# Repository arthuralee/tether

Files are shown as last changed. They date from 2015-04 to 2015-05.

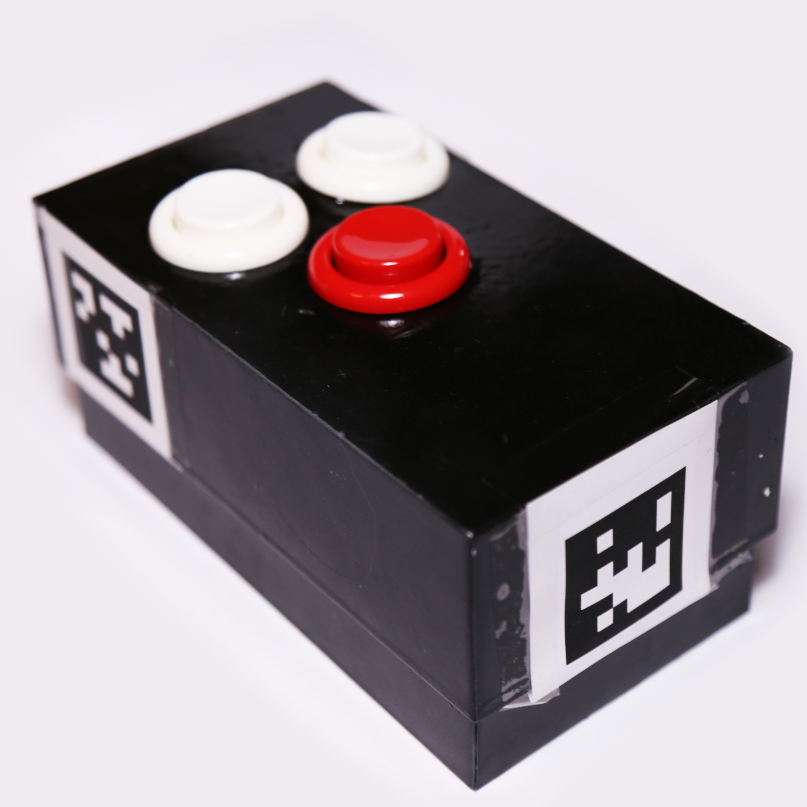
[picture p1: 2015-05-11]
poster/IMG_2027.JPG

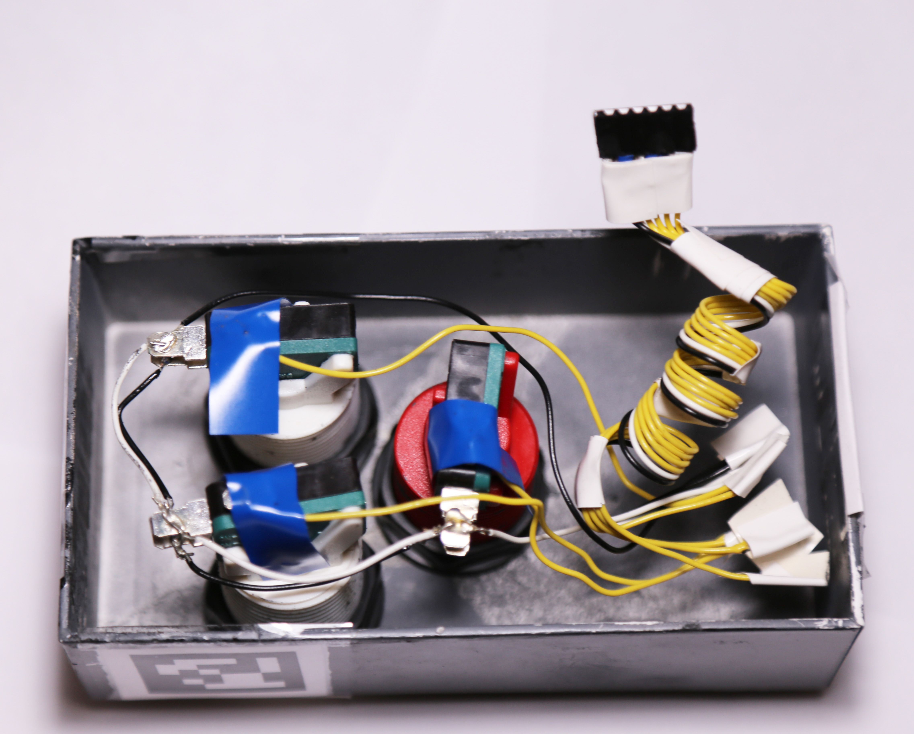
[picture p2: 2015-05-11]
poster/IMG_2029.JPG

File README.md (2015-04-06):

# Tether

## Tether provides real-time tracking of physical objects.
Tether tracks the orientation and position of an object in 3D space, making the data available for use in the construction of a 3D world.

http://www.ece.cmu.edu/~ece549/spring15/team05/

This is our project repository, which will contain code for all parts of the project.

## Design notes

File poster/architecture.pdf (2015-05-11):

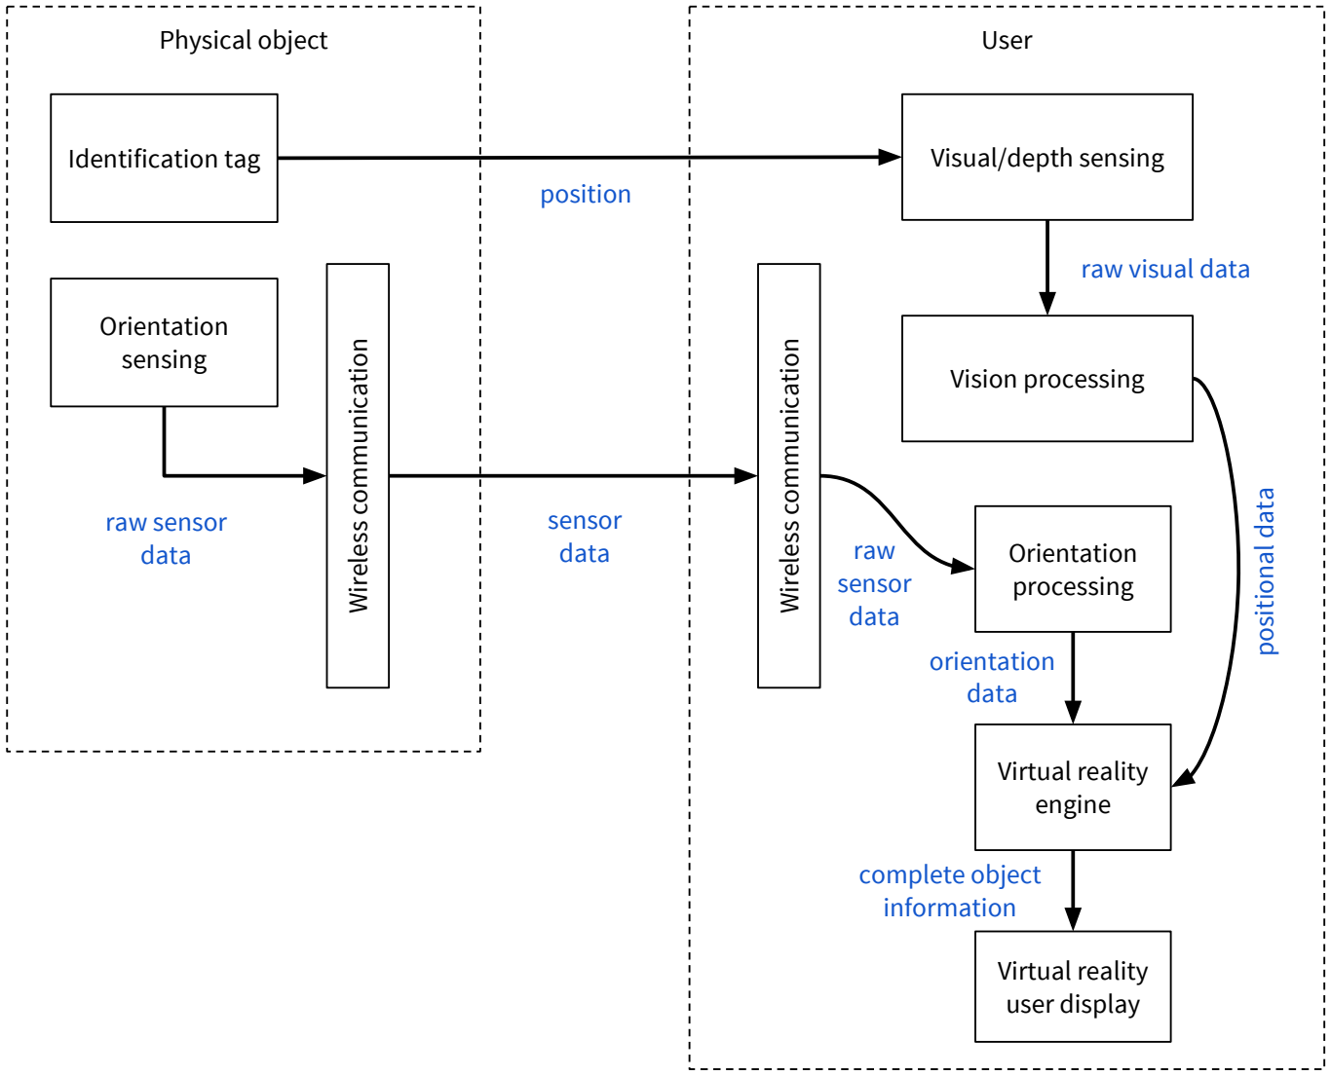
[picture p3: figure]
Physical object; User; Orientation sensing; Identification tag; Visual/depth sensing; Vision processing; Virtual reality engine; Orientation processing; Wireless communication; sensor data; Virtual reality user display; raw sensor data; position; raw visual data; positional data; orientation data; complete object information

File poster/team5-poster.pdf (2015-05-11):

# tether

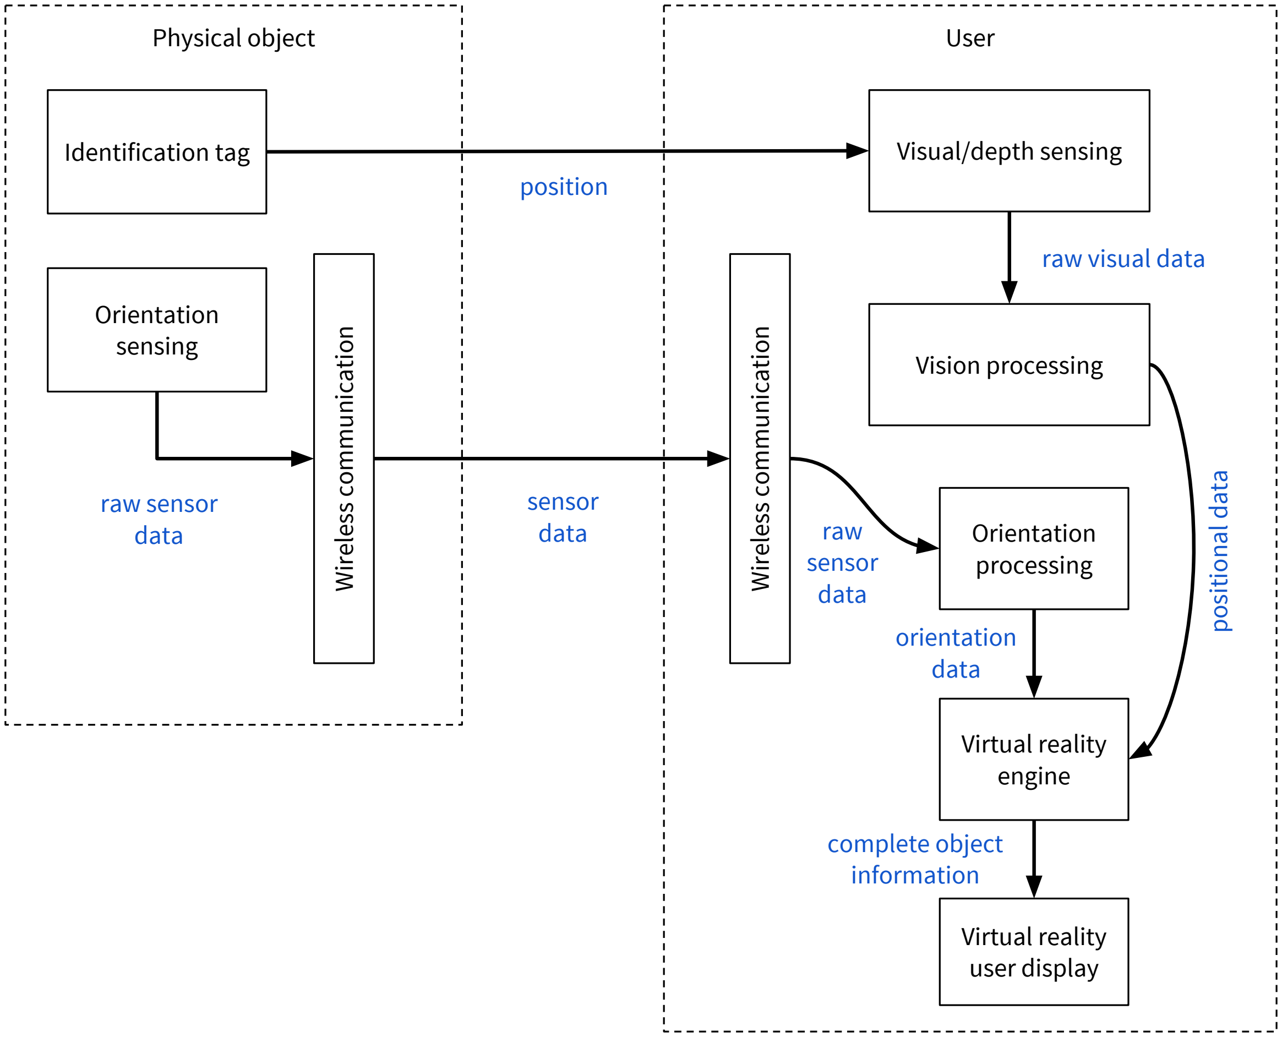
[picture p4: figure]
Physical object; User; Orientation sensing; Identification tag; Visual/depth sensing; Vision processing; Virtual reality engine; Orientation processing; Wireless communication; sensor data; Virtual reality user display; raw sensor data; position; raw visual data; positional data; orientation data; complete object information
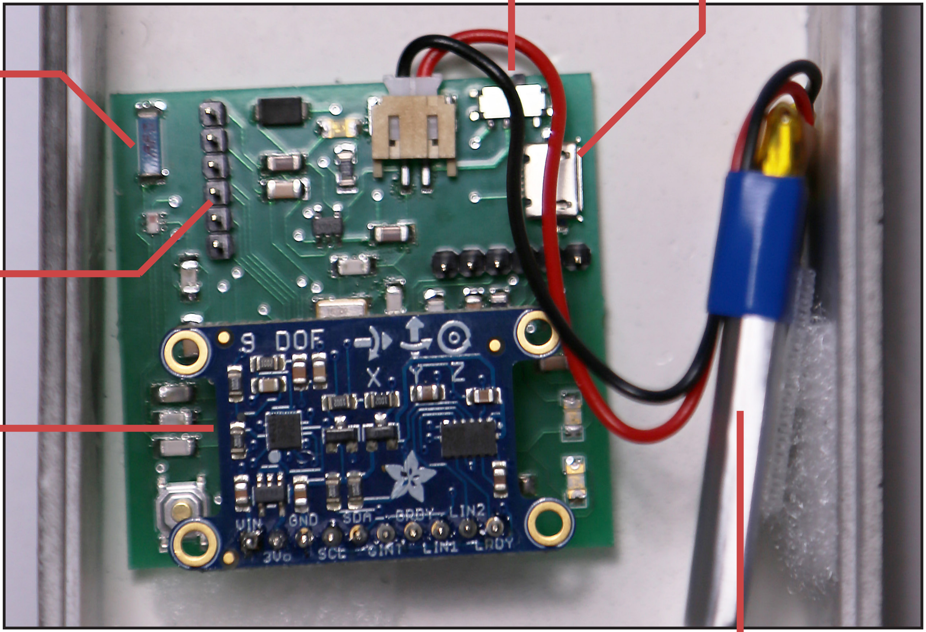
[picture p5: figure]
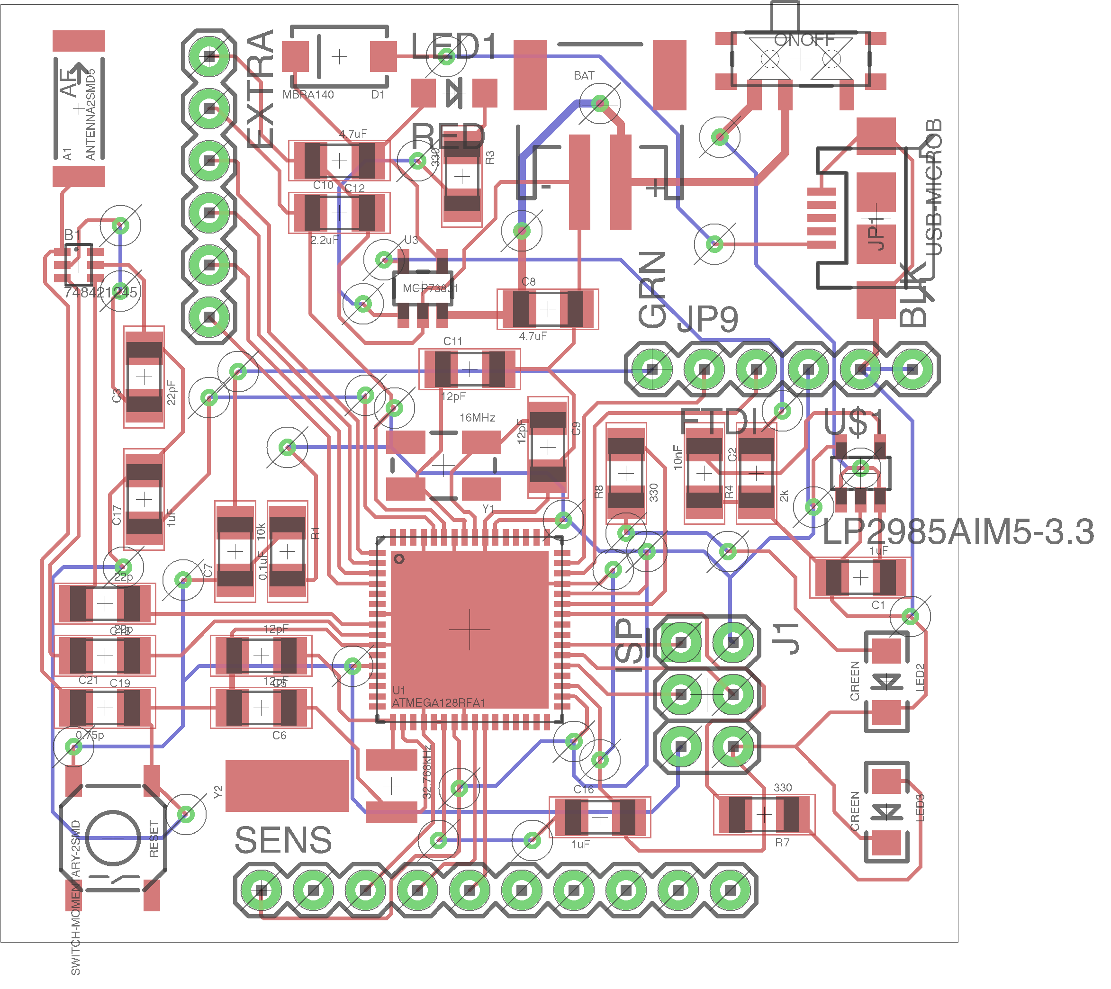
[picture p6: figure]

18-549 Embedded Systems Design - Spring 2015

Electrical & Computer Engineering Department Carnegie Mellon University

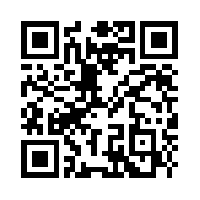
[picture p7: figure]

Tomer Borenstein
tborenst@andrew.cmu.edu

Arthur Lee
arthurle@andrew.cmu.edu

Ahmed Shalaby
akshalab@andrew.cmu.edu
Introduction | Architecture

# Sensor box design

# Hardware

Tether brings physical objects into the virtual world
so that users can interact with them in both worlds simultaneously. Tether creates a compelling way to interact with virtual objects, which could be viable in many fields from video gaming to engineering and medicine.

enclosure
april tags

buttons

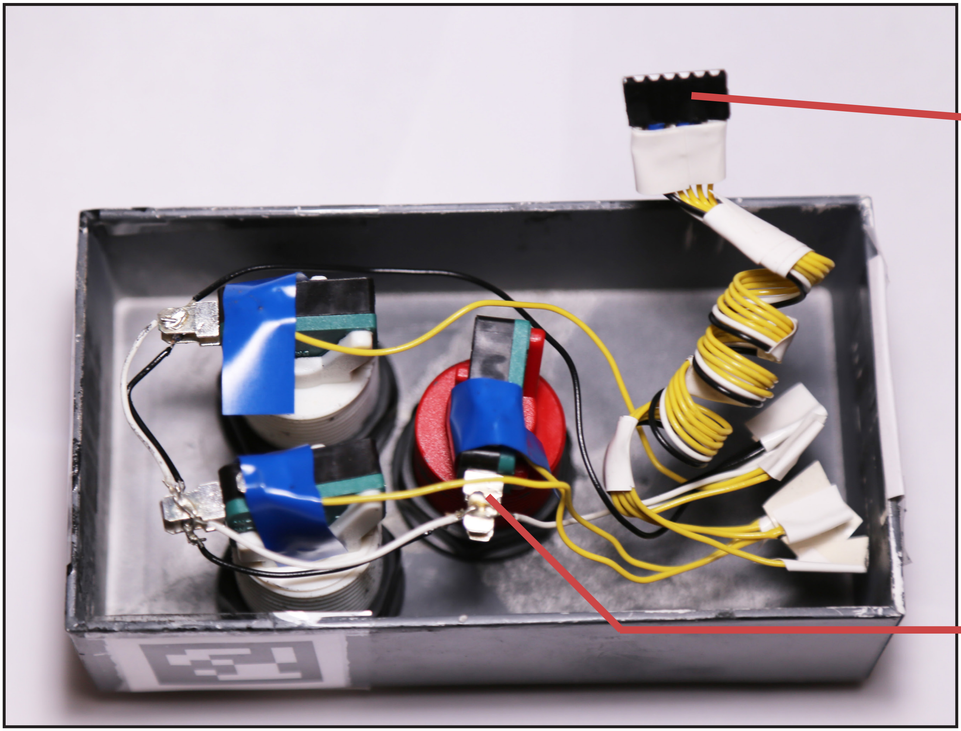
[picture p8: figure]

lithium-polymer
battery

USB
charging

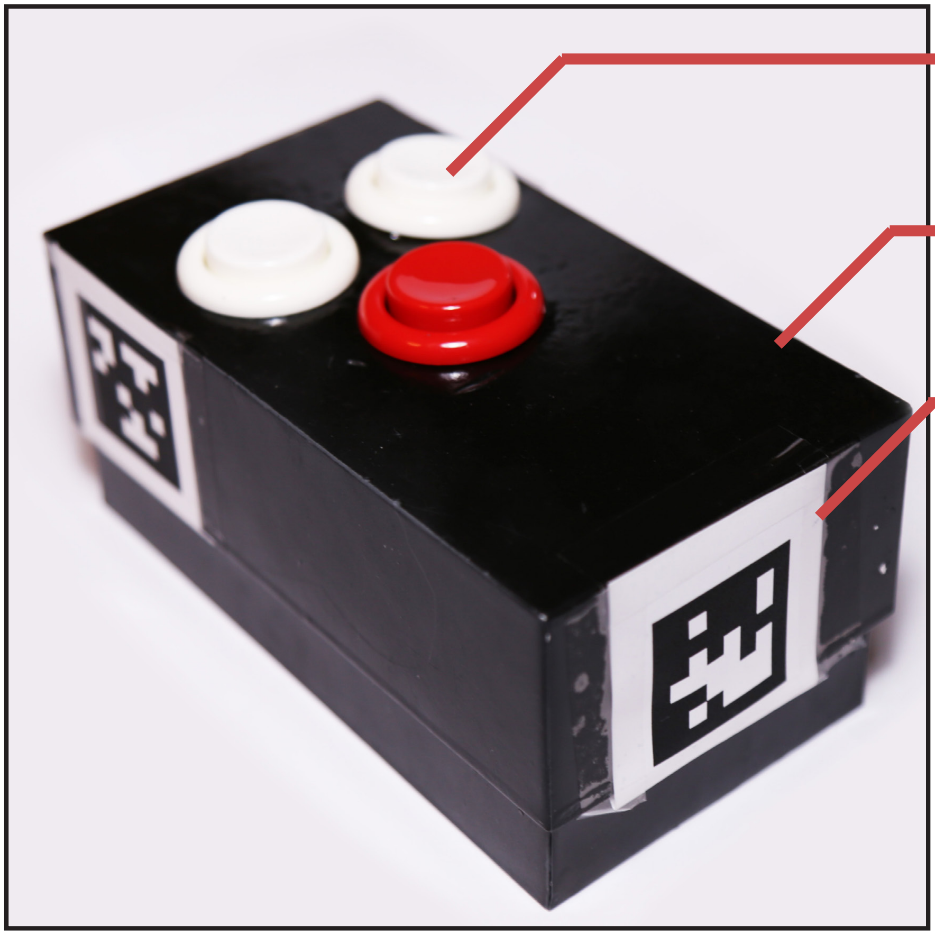
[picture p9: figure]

on-board
antenna
expansion port

9DOF sensor
breakout

arcade buttons

expansion port
connector

on/off switch

The ATMega128RFA1 has
an integrated radio, which allows us to send sensor
data wirelessly using the
802.15.4 protocol. The
receiver uses the same
PCB, and interfaces with
the computer via serial.
We connected an Adafruit 9DOF sensor breakout board to the PCB via header pins at the bottom. The expansion port on the left gives direct access to ADC so that buttons, switches and dials can easily be connected to the sensor. Additionally, the unit runs on LiPo batteries with USB charging.
We used AprilTags and a network camera to track the 3D position of the sensor box.

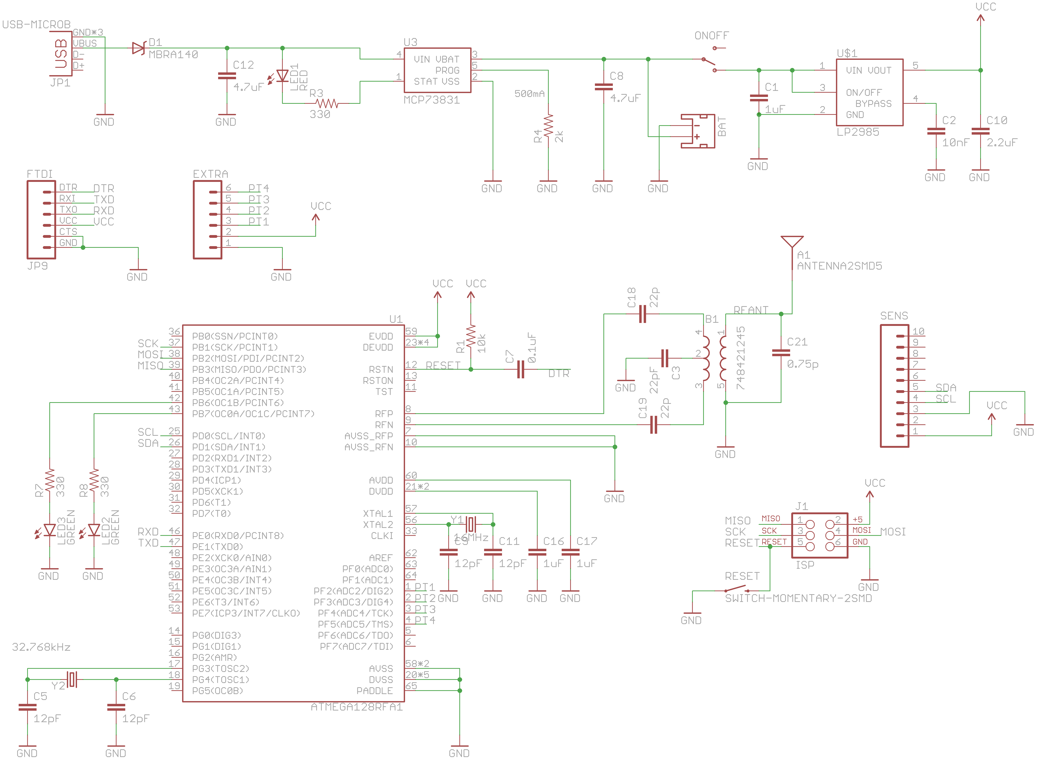
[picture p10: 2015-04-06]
website/images/media/20140401-schematic.png

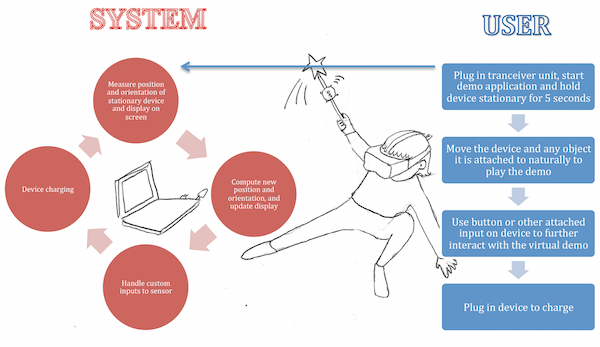
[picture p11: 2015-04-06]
website/images/behavior.png

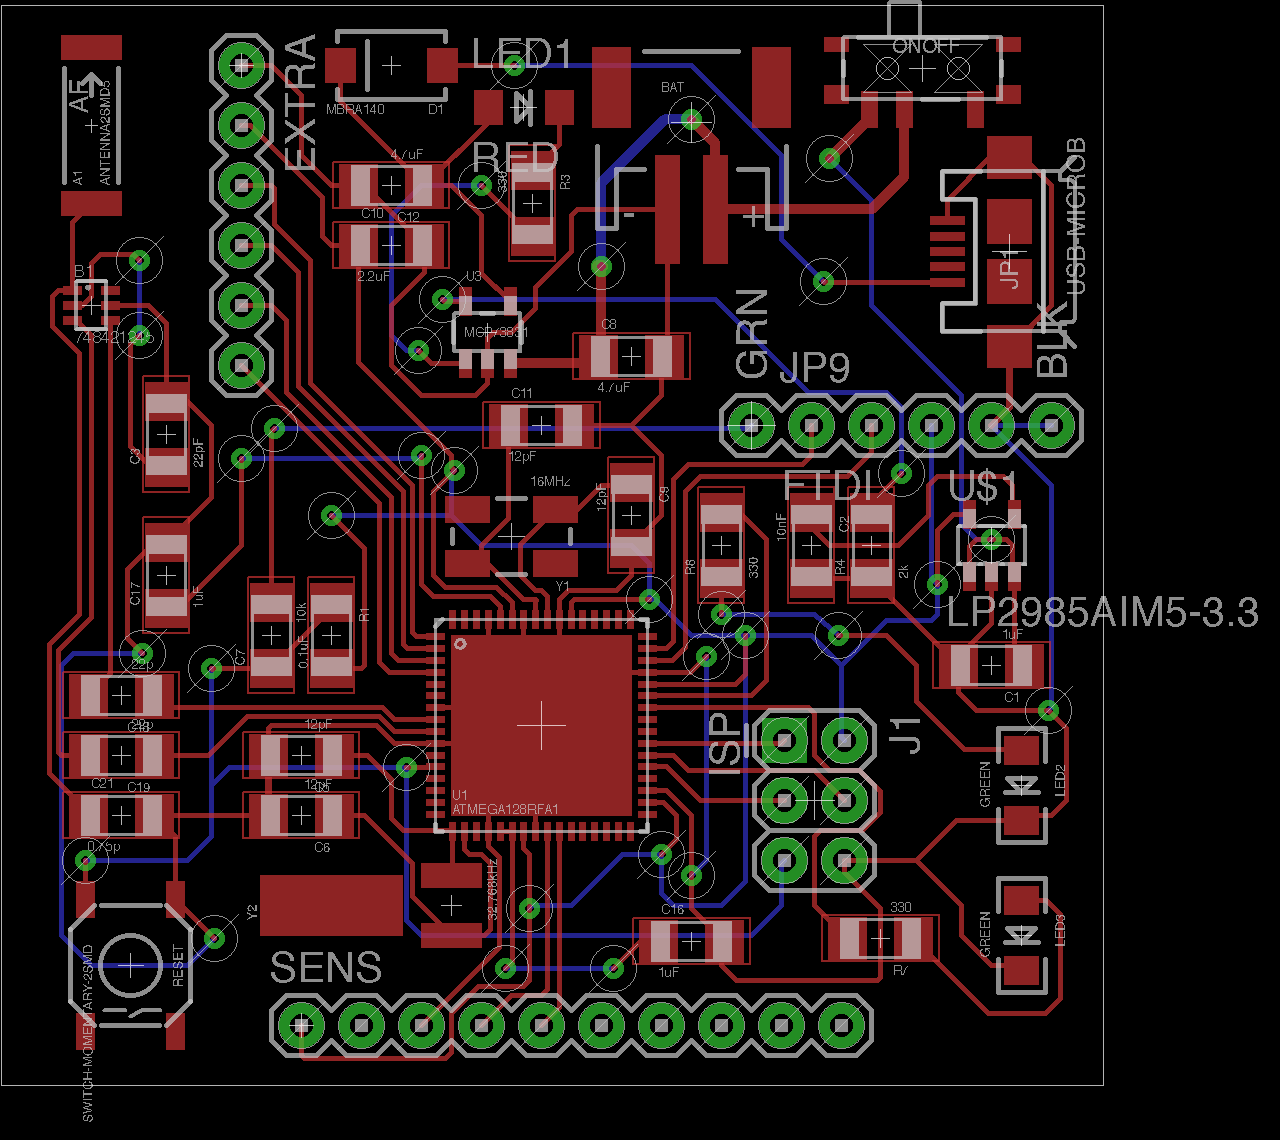
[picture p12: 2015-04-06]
website/images/media/20140401-board.png

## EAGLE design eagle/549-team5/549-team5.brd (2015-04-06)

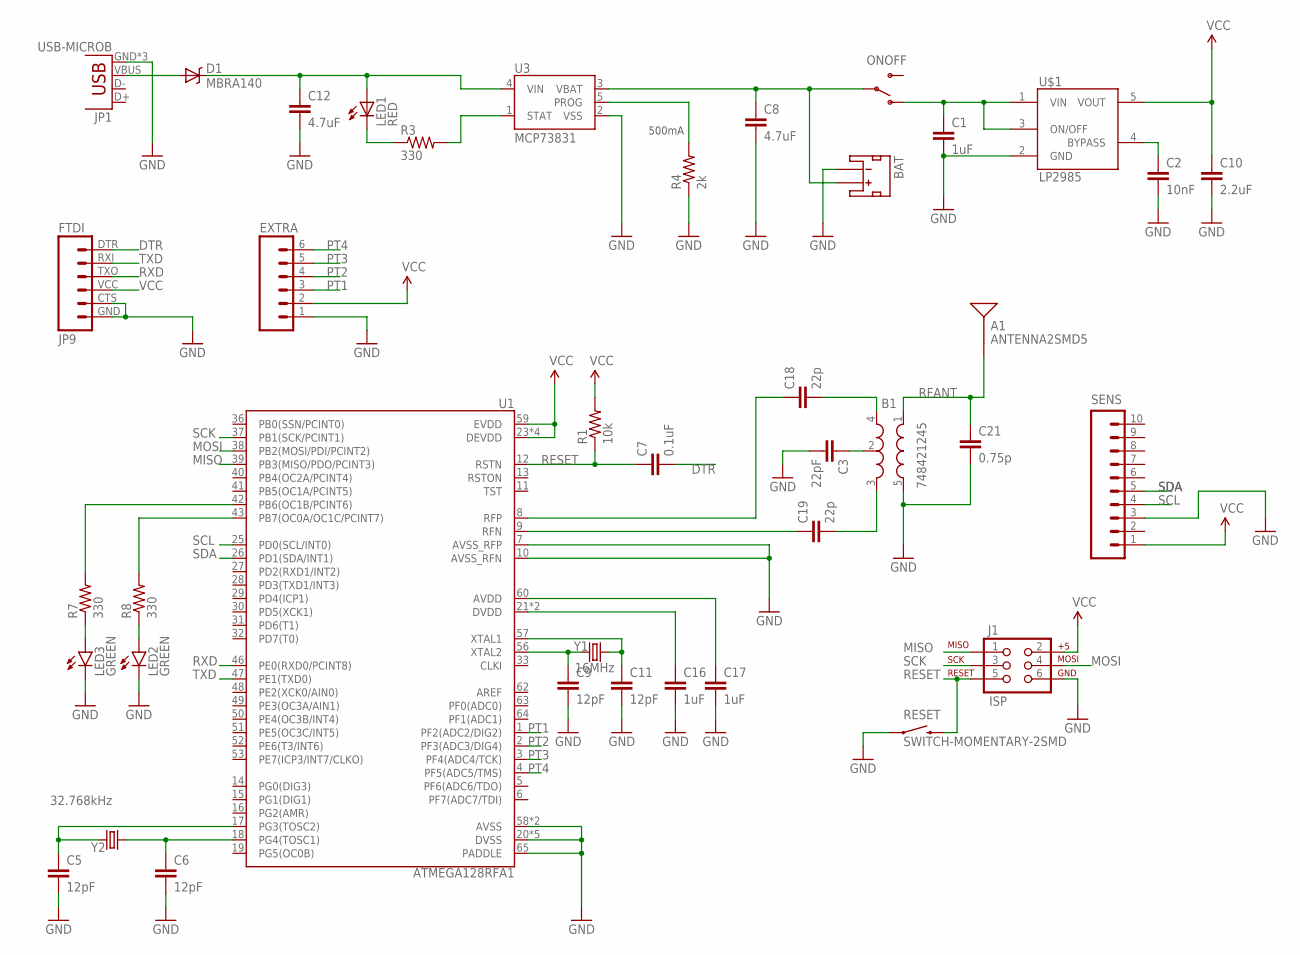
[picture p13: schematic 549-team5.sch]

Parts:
A1: ANTENNA2SMD5; ANTENNA-CHIP5
B1: 748421245; BALUN
BAT: JST_2MM_MALE; JST-2-SMD
C1, C16, C17: 1uF; 1206
C2: 10nF; 1206
C3: 22pF; 1206
C5, C6, C9, C11: 12pF; 1206
C7: 0.1uF; 1206
C8, C12: 4.7uF; 1206
C10: 2.2uF; 1206
C18, C19: 22p; 1206
C21: 0.75p; 1206
D1: MBRA140; SMA-DIODE
EXTRA: M06SILK_FEMALE_PTH; 1X06
J1: ISP; 2X3-NS
JP1: USB-MICROB
JP9: FTDI; FTDI_BASIC
LED1: RED; LED-1206
LED2, LED3: GREEN; LED-1206
ONOFF: SWITCH-SPST-SMD-A
R1: 10k; 1206
R3, R7, R8: 330; 1206
R4: 2k; 1206
RESET: SWITCH-MOMENTARY-2SMD; TACTILE-SWITCH-SMD
SENS: M10SILK_FEMALE_PTH; 1X10
U1: ATMEGA128RFA1; QFN-64
U3: MCP73831; SOT23-5
U$1: LP2985AIM5-3.3; SOT25
Y1: 16MHz; CRYSTAL-SMD-5X3
Y2: 32.768kHz; CRYSTAL-32KHZ-SMD

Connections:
AVDD: C17.1, U1.60 (AVDD)
BYPASS: C2.1, U$1.4 (BYPASS)
DTR: C7.2, JP9.DTR (1)
DVDD: C16.1, U1.21 (DVDD), U1.22 (DVDD)
GND: B1.5 (GND), BAT.1 (-), C1.2, C2.2, C3.2, C5.2, C6.2, C8.2, C9.2, C10.2, C11.2, C12.2, C16.2, C17.2, C21.2, EXTRA.1, J1.6, JP1.GND, JP1.MT1 (GND), JP1.MT2 (GND), JP9.CTS (5), JP9.GND (6), LED2.C, LED3.C, R4.1, RESET.1, SENS.3, U1.7 (AVSS_RFP), U1.10 (AVSS_RFN), U1.20 (DVSS), U1.24 (DVSS), U1.35 (DVSS), U1.45 (DVSS), U1.55 (DVSS), U1.58 (AVSS), U1.61 (AVSS), U1.65 (PADDLE), U3.2 (VSS), U$1.2 (GND)
MISO: J1.1, U1.39 (PB3(MISO/PDO/PCINT3))
MOSI: J1.4, U1.38 (PB2(MOSI/PDI/PCINT2))
unnamed: R8.2, U1.43 (PB7(OC0A/OC1C/PCINT7))
unnamed: C11.1, U1.57 (XTAL1), Y1.3 (2)
unnamed: C9.1, U1.56 (XTAL2), Y1.1
unnamed: C6.1, U1.18 (PG4(TOSC1)), Y2.X1 (1)
unnamed: C5.1, U1.17 (PG3(TOSC2)), Y2.X2 (2)
unnamed: C1.1, ONOFF.1 (O), U$1.1 (VIN), U$1.3 (ON/OFF)
unnamed: LED3.A, R7.1
unnamed: BAT.2 (+), C8.1, ONOFF.2, U3.3 (VBAT)
unnamed: B1.4 (OUT1), C18.2
unnamed: B1.3 (OUT2), C19.2
unnamed: R7.2, U1.42 (PB6(OC1B/PCINT6))
unnamed: LED2.A, R8.1
unnamed: B1.2 (GND), C3.1
unnamed: C12.1, D1.C, LED1.A, U3.4 (VIN)
unnamed: R3.2, U3.1 (STAT)
unnamed: LED1.C, R3.1
unnamed: D1.A, JP1.VBUS
PROG: R4.2, U3.5 (PROG)
PT1: EXTRA.3, U1.1 (PF2(ADC2/DIG2))
PT2: EXTRA.4, U1.2 (PF3(ADC3/DIG4))
PT3: EXTRA.5, U1.3 (PF4(ADC4/TCK))
PT4: EXTRA.6, U1.4 (PF5(ADC5/TMS))
RESET: C7.1, J1.5, R1.1, RESET.3 (2), U1.12 (RSTN)
RFANT: A1.FEED, B1.1 (IN), C21.1
RFN: C19.1, U1.9 (RFN)
RFP: C18.1, U1.8 (RFP)
RXD: JP9.TXO (3), U1.46 (PE0(RXD0/PCINT8))
SCK: J1.3, U1.37 (PB1(SCK/PCINT1))
SCL: SENS.4, U1.25 (PD0(SCL/INT0))
SDA: SENS.5, U1.26 (PD1(SDA/INT1))
TXD: JP9.RXI (2), U1.47 (PE1(TXD0))
VCC: C10.1, EXTRA.2, J1.2, JP9.VCC (4), R1.2, SENS.1, U1.23 (DEVDD), U1.34 (DEVDD), U1.44 (DEVDD), U1.54 (DEVDD), U1.59 (EVDD), U$1.5 (VOUT)

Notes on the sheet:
500mA

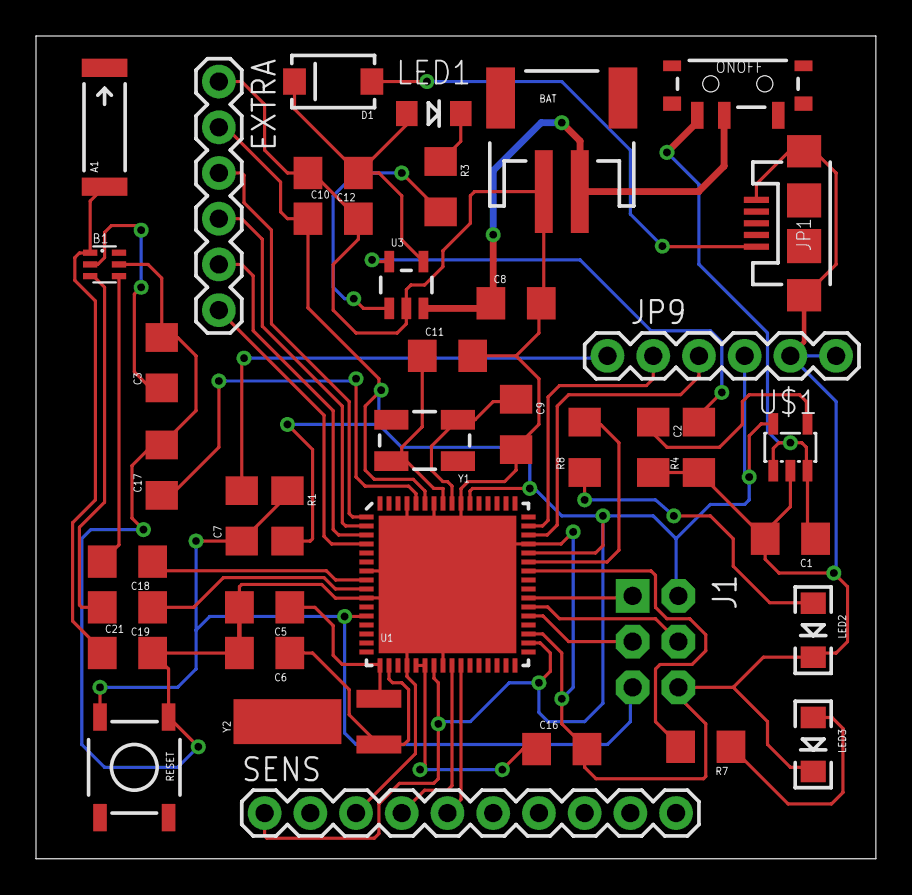
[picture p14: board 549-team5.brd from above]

Board: 2 copper layers, 46.7 x 45.7 mm, 40 parts (0 on the bottom side), 39 nets.

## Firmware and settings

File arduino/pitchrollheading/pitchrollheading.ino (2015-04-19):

#include <Wire.h>
#include <Adafruit_Sensor.h>
#include <Adafruit_LSM303_U.h>
#include <Adafruit_L3GD20_U.h>
#include <Adafruit_9DOF.h>

/* Assign a unique ID to the sensors */
Adafruit_9DOF                dof   = Adafruit_9DOF();
Adafruit_LSM303_Accel_Unified accel = Adafruit_LSM303_Accel_Unified(30301);
Adafruit_LSM303_Mag_Unified   mag   = Adafruit_LSM303_Mag_Unified(30302);
Adafruit_L3GD20_Unified      gyr   = Adafruit_L3GD20_Unified(30303);

/* Update this with the correct SLP for accurate altitude measurements */
float seaLevelPressure = SENSORS_PRESSURE_SEALEVELHPA;

/**************************************************************************/
/*!
    @brief  Initialises all the sensors used by this example
*/
/**************************************************************************/
void initSensors()
{
  if(!accel.begin())
  {
    /* There was a problem detecting the LSM303 ... check your connections */
    Serial.println(F("Ooops, no LSM303 detected ... Check your wiring!"));
    while(1);
  }
  if(!mag.begin())
  {
    /* There was a problem detecting the LSM303 ... check your connections */
    Serial.println("Ooops, no LSM303 detected ... Check your wiring!");
    while(1);
  }
  if(!gyr.begin())
  {
    /* There was a problem detecting the LSM303 ... check your connections */
    Serial.println("Ooops, no L3GD20 detected ... Check your wiring!");
    while(1);
  }
}

/**************************************************************************/
/*!

*/
/**************************************************************************/
void setup(void)
{
  Serial.begin(115200);
  
  /* Initialise the sensors */
  initSensors();
}

/**************************************************************************/
/*!
    @brief  Constantly check the roll/pitch/heading/altitude/temperature
*/
/**************************************************************************/
void loop(void)
{
  sensors_event_t accel_event;
  sensors_event_t mag_event;
  sensors_event_t gyr_event;
  sensors_vec_t   orientation;

  /* Calculate pitch and roll from the raw accelerometer data */
  if(!accel.getEvent(&accel_event)) return;
  if (dof.fusionGetOrientation(&accel_event, &mag_event, &orientation))
  {
    /* 'orientation' should have valid .roll and .pitch fields */
    Serial.print(orientation.roll); //roll
//    if(orientation.roll<=0){
//      Serial.print(-orientation.roll); //roll
//    }
//    else{
//      Serial.print(360-orientation.roll); //roll
//    }
    Serial.print(F(","));
    Serial.print(orientation.pitch); //pitch
//    if(orientation.pitch<0){
//      Serial.print(-orientation.pitch); //pitch
//    }
//    else{
//      Serial.print(360-orientation.pitch); //pitch
//    }
  }
  Serial.print(F(","));
  /* Calculate x y z from gyroscope */
  if (!gyr.getEvent(&gyr_event)) return;
  else {
    /* 'orientation' should have valid .roll and .pitch fields */
    Serial.print(gyr_event.gyro.x); //gyr x
    Serial.print(F(","));
    Serial.print(gyr_event.gyro.y); //gyr y
    Serial.print(F(","));
    Serial.print(gyr_event.gyro.z); //gyr z

  }
//  else{
//    Serial.print(F(" ")); //gyr x
//    Serial.print(F(","));
//    Serial.print(F(" ")); //gyr y
//    Serial.print(F(","));
//    Serial.print(F(" ")); //gyr z
//  }
  Serial.print(F(","));
  /* Calculate the heading using the magnetometer */
  if(!mag.getEvent(&mag_event)) return;
//  dof.magTiltCompensation(SENSOR_AXIS_Z, &mag_event, &accel_event);
  if (dof.fusionGetOrientation(&accel_event, &mag_event, &orientation))
  {
    /* 'orientation' should have valid .heading data now */
    Serial.print(orientation.heading); //Headin
  }

  Serial.println(F(""));
  delay(100);
}

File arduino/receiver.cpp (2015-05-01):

#include <Wire.h>

#include "Arduino.h"
#include "RadioFunctions.h"

void setup(void);
void loop(void);

void setup(void)
{
  Serial.begin(115200);

  rfBegin(11);

  Serial.println("Setup");

  /* Initialise the sensors */
  //initSensors();
}

/**************************************************************************/
/*!
    @brief  Constantly check the roll/pitch/heading/altitude/temperature
*/
/**************************************************************************/
void loop() {
  if (rfAvailable()) {
    Serial.print(rfRead());
  }
}

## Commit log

2015-04-06 Added eagle files
    [549-team5.brd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]
2015-04-06 Added media with pics of schematic and board
2015-04-19 arduino code, libraries and main
2015-04-20 Added cpp versions of arduino code with Makefile
2015-04-27 sensor data and filter in unity c#
2015-04-29 [tether-cam] Fixed case for TCP files
2015-05-01 Updated sensor printing
2015-05-02 Added button code for PCB
2015-05-06 Fixed robustness for serialServer
    [serialServer.py]

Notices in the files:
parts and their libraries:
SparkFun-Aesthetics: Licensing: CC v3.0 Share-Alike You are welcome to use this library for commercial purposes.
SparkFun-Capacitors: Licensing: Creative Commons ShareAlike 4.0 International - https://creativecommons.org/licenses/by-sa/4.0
